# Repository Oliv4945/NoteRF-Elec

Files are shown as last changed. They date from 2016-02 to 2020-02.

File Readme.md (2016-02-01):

# NodeRF

RF sensors and actuators based on ATMega328 and RFM69hw from hopeRF.  
Arduino bootloader is used in order to use all available libraries

## NoteGateway
Gateway with serial output. It just collects data from RF sensors and send it through serial link.  
Configuration is explained in configuration.h file

Serial messages are really simple for now and formated like `sensorNumber|dataType|Data1|Data2|DataX|batteryLevel|RSSI`  
For example, the sensor N°5, type temperature (16.50°C) and humidity (55.3%) with a battery level of 3.98V is `5|1|1650|5530|398|-53`

## NoteSensor
Sensors' code.  
You just have to set config.h to suit your needs. Also uncommenting a `#define DATA_SENSORNAME` will activate it.

## Schematics
Hardware source files made with Eagle 7.3.0 + [Spakfun library](https://github.com/sparkfun/SparkFun-Eagle-Libraries)

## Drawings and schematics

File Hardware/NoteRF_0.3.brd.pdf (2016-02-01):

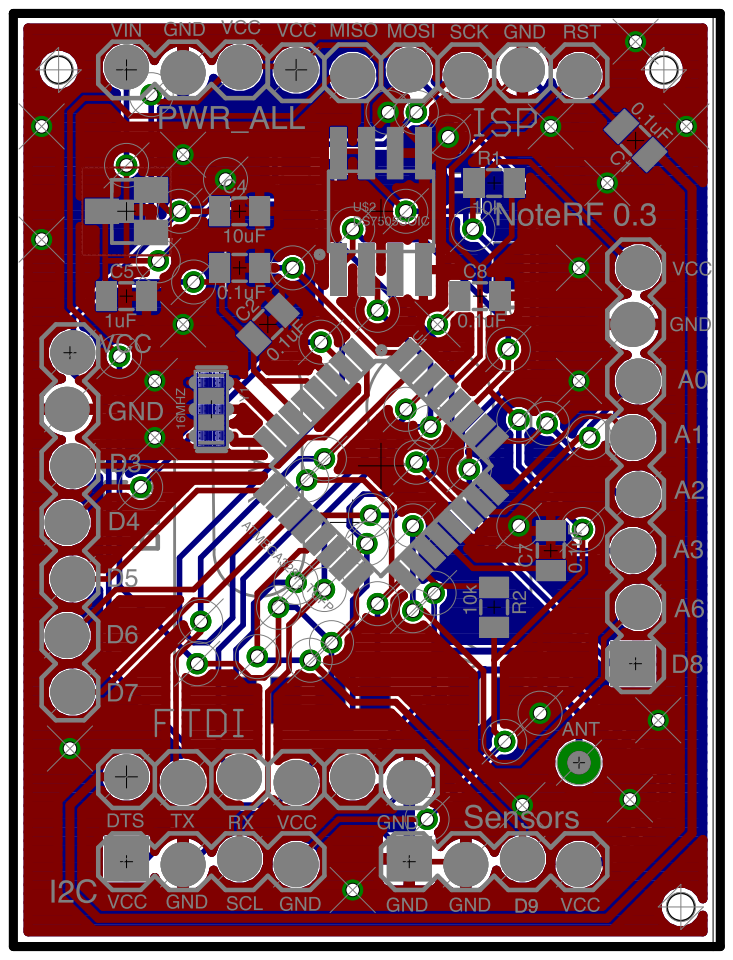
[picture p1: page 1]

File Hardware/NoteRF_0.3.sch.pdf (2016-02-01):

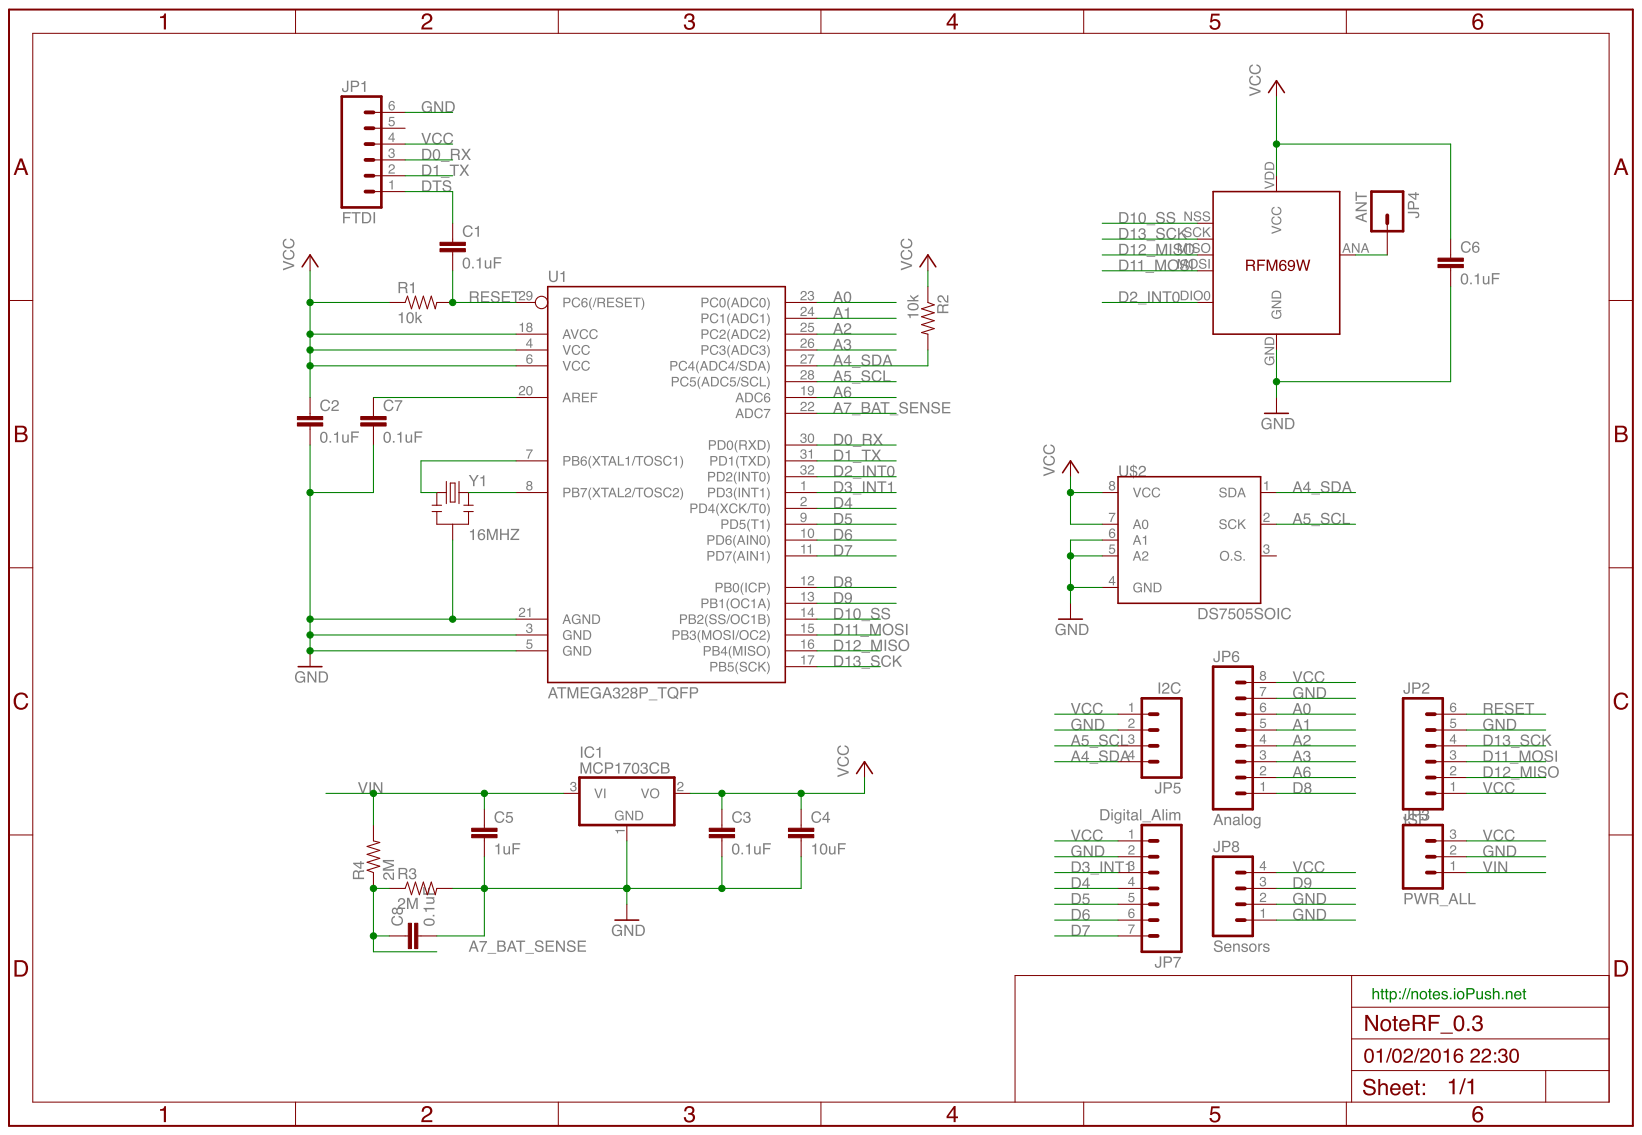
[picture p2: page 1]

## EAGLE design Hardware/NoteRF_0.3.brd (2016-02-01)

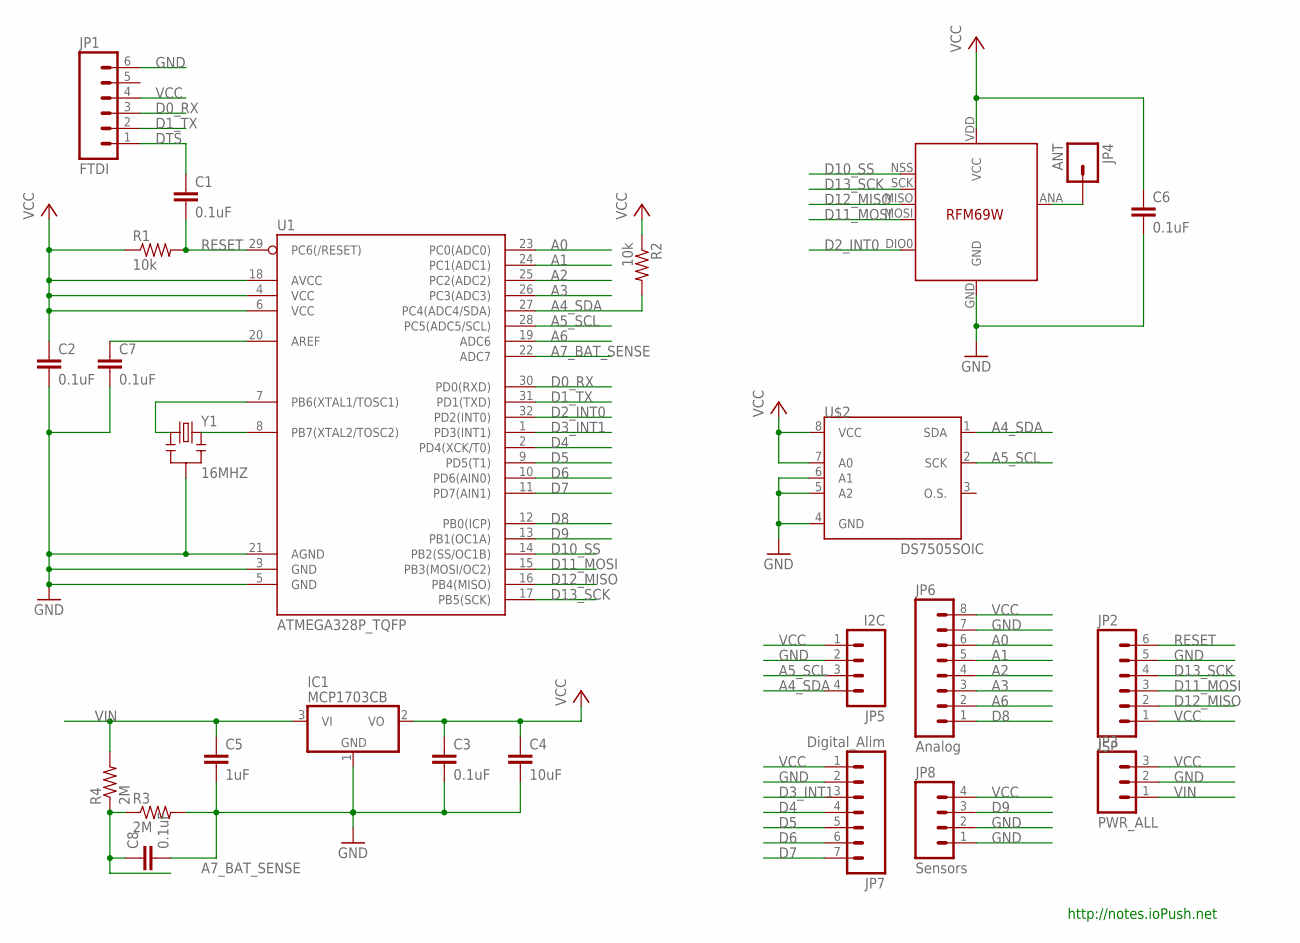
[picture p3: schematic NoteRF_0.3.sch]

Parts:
C1, C2, C3, C6, C7, C8: 0.1uF; 0805
C4: 10uF; 0805
C5: 1uF; 0805
IC1: MCP1703CB; SOT23
JP1: FTDI; 1X06_LOCK
JP2: ISP; 1X06_LOCK
JP3: PWR_ALL; 1X03_LOCK
JP4: ANT; 1X01NS-KIT
JP5: I2C; 1X04_LOCK
JP6: Analog; 1X08_LOCK
JP7: Digital_Alim; 1X07_LOCK
JP8: Sensors; 1X04_LOCK
R1, R2: 10k; 0805
R3, R4: 2M; 0805
U1: ATMEGA328P_TQFP; TQFP32-08
U$1: RFM69; RFM69W-MINPADS
U$2: DS7505SOIC; SO08
Y1: 16MHZ; RESONATOR-SMD

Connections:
A0: JP6.6, U1.23 (PC0(ADC0))
A1: JP6.5, U1.24 (PC1(ADC1))
A2: JP6.4, U1.25 (PC2(ADC2))
A3: JP6.3, U1.26 (PC3(ADC3))
A4_SDA: JP5.4, R2.2, U1.27 (PC4(ADC4/SDA)), U$2.1 (SDA)
A5_SCL: JP5.3, U1.28 (PC5(ADC5/SCL)), U$2.2 (SCK)
A6: JP6.2, U1.19 (ADC6)
A7_BAT_SENSE: C8.1, R3.1, R4.1, U1.22 (ADC7)
D0_RX: JP1.3, U1.30 (PD0(RXD))
D1_TX: JP1.2, U1.31 (PD1(TXD))
D2_INT0: U1.32 (PD2(INT0)), U$1.DIO0
D3_INT1: JP7.3, U1.1 (PD3(INT1))
D4: JP7.4, U1.2 (PD4(XCK/T0))
D5: JP7.5, U1.9 (PD5(T1))
D6: JP7.6, U1.10 (PD6(AIN0))
D7: JP7.7, U1.11 (PD7(AIN1))
D8: JP6.1, U1.12 (PB0(ICP))
D9: JP8.3, U1.13 (PB1(OC1A))
D10_SS: U1.14 (PB2(SS/OC1B)), U$1.NSS (SEL)
D11_MOSI: JP2.3, U1.15 (PB3(MOSI/OC2)), U$1.MOSI
D12_MISO: JP2.2, U1.16 (PB4(MISO)), U$1.MISO
D13_SCK: JP2.4, U1.17 (PB5(SCK)), U$1.SCK
DTS: C1.1, JP1.1
GND: C2.2, C3.2, C4.2, C5.2, C6.2, C7.2, C8.2, IC1.1 (GND), JP1.6, JP2.5, JP3.2, JP5.2, JP6.7, JP7.2, JP8.1, JP8.2, R3.2, U1.3 (GND), U1.5 (GND), U1.21 (AGND), U$1.GND, U$2.4 (GND), U$2.5 (A2), U$2.6 (A1), Y1.2
unnamed: JP4.1, U$1.ANA (ANT)
unnamed: C7.1, U1.20 (AREF)
unnamed: U1.8 (PB7(XTAL2/TOSC2)), Y1.3
unnamed: U1.7 (PB6(XTAL1/TOSC1)), Y1.1
RESET: C1.2, JP2.6, R1.2, U1.29 (PC6(/RESET))
VCC: C2.1, C3.1, C4.1, C6.1, IC1.2 (VO), JP1.4, JP2.1, JP3.3, JP5.1, JP6.8, JP7.1, JP8.4, R1.1, R2.1, U1.4 (VCC), U1.6 (VCC), U1.18 (AVCC), U$1.VDD (VCC), U$2.7 (A0), U$2.8 (VCC)
VIN: C5.1, IC1.3 (VI), JP3.1, R4.2

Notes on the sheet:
http://notes.ioPush.net

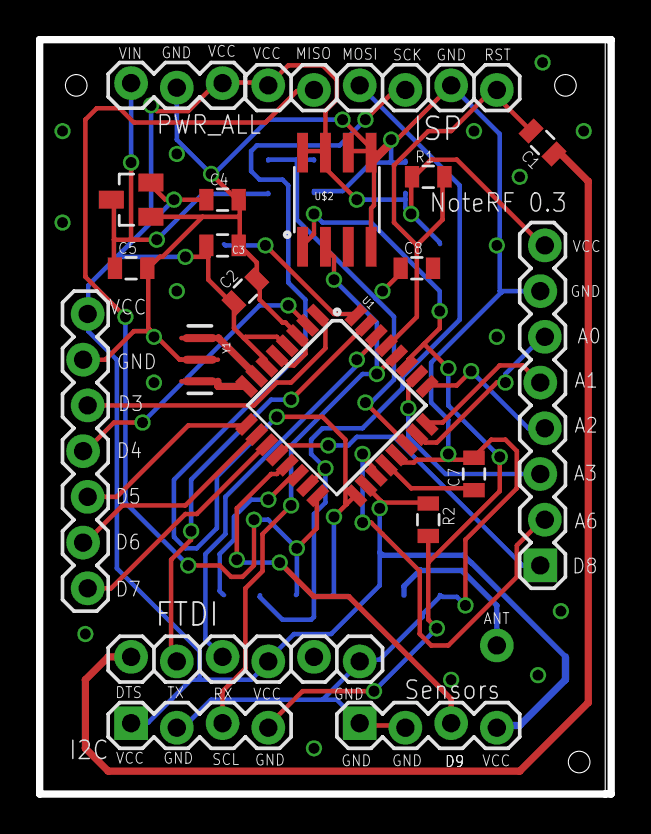
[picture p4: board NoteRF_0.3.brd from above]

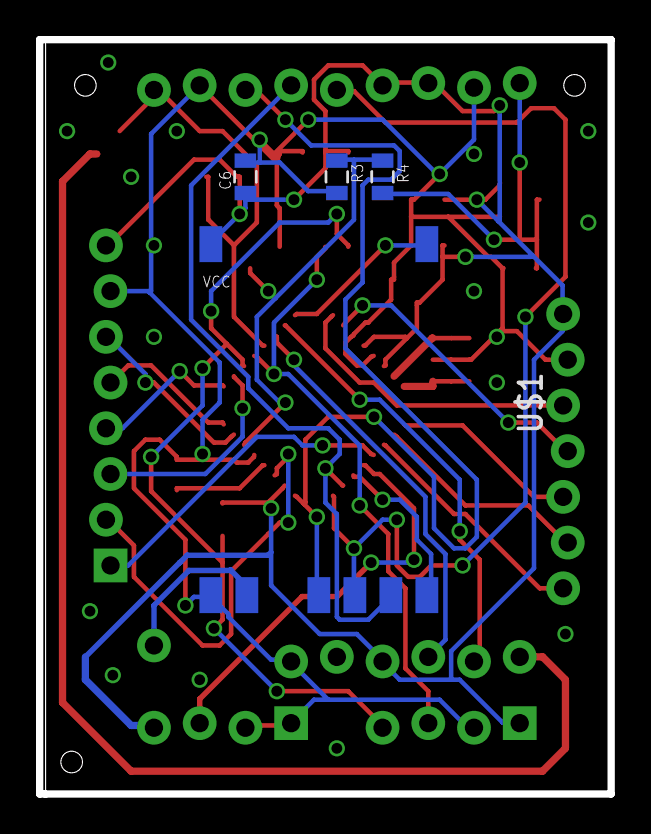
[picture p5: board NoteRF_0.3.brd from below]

Board: 2 copper layers, 31.8 x 41.9 mm, 25 parts (4 on the bottom side), 31 nets.

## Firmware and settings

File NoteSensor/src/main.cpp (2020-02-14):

// Includes
#include <Arduino.h>
#include <RFM69.h>    // Get it here: https://www.github.com/lowpowerlab/rfm69
#include <SPI.h>
#include <LowPower.h>
#include "configuration.h"
#ifdef DATA_DHT22
  #include <dht.h>
#endif
#ifdef DATA_TELEINFOCLIENT
  #include <SoftwareSerial.h>
  #include <TeleInfoClient.h>
#endif
#ifdef DATA_BMP
  // From https://github.com/jrowberg/i2cdevlib/tree/master/Arduino/BMP085
  #include "Wire.h"
  #include "I2Cdev.h"
  #include "BMP085.h"
#endif
#ifdef DATA_VL53L0X
  #include <Wire.h>
  #include <VL53L0X.h>
#endif

// Activate/desactivate debug with only one #define
// From low power lab :)
#ifdef DEBUG_ON 
  #define DEBUG( input )    { Serial.print(input); delay(1); }
  #define DEBUGDec( input ) { Serial.print( input, DEC); delay(1); }
  #define DEBUGHex( input ) { Serial.print(input, HEX); delay(1); }
  #define DEBUGln( input )  { Serial.println(input); delay(1); }
#else
  #define DEBUG(input);
  #define DEBUGDec( input )
  #define DEBUGHex( input )
  #define DEBUGln(input);
#endif


// Others - This data has not to be configured
#define DATA_STRING    0


// Structures
#ifdef DATA_DHT22
  struct DHT22Data {
    int16_t temperature;
    uint16_t humidity;
  };
#endif
#ifdef DATA_TELEINFOCLIENT
  struct TeleInfoClientData {
    unsigned long indexHC;
    unsigned long indexHP;
    unsigned int iinst;
    unsigned int papp;
  };
#endif
#ifdef DATA_DS18B20
  struct DS18B20Data {
    int16_t temperature;
    uint16_t humidity;
  };
#endif
#ifdef DATA_BMP
  struct BMPData {
    int16_t temperature;
    uint32_t pressure;
  };
#endif

// Objects and globals
RFM69 radio;
#ifdef DATA_DHT22
  dht DHT22;
#endif
#ifdef DATA_TELEINFOCLIENT
  TeleInfoClient tic( 3, 10, 11 );
#endif
#ifdef DATA_BMP
  BMP085 barometer;
#endif
#ifdef DATA_INTERRUPT
  uint8_t interruptData;
#endif

#ifdef DATA_VL53L0X
  VL53L0X tof;
#endif
  

void setup() {
  
  // Serial init.
  #ifdef DEBUG_ON
    Serial.begin( SERIAL_BAUD );
  #endif
  DEBUG( "SensorRF - NodeID : " );
  DEBUGln( RFM_NODEID );
  
  // RFM69 init.
  DEBUG( "RFM69 - Initialisation" );
  radio.initialize( RFM_FREQUENCY, RFM_NODEID, RFM_NETWORKID );
  DEBUG( "RFM69 - Initialised" );
  #ifdef RFM_IS_RFM69HW
    radio.setHighPower( true );
  #endif
  radio.encrypt( RFM_ENCRYPTKEY );
  radio.setPowerLevel( RFM_POWER_LEVEL );
  //radio.setFrequency( 919000000 ); //set frequency to some custom frequency - TBC
  char buff[50];
  sprintf( buff, "\nTransmitting at %d Mhz...", RFM_FREQUENCY==RF69_433MHZ ? 433 : RFM_FREQUENCY==RF69_868MHZ ? 868 : 915 );
  DEBUGln( buff );
  delay( 10 );
  
  
  #ifdef DATA_DHT22
    // Pins
    pinMode( PIN_DHT22_POWER, OUTPUT );
    // DHT22 check
    digitalWrite( PIN_DHT22_POWER, HIGH );                   // Power the DHT22
    LowPower.powerDown( SLEEP_4S, ADC_OFF, BOD_OFF );        // Wait DHT22 start
    int chk = DHT22.read22( PIN_DHT22_DATA );
    switch ( chk ) {
    case DHTLIB_OK:
        DEBUG("DHT22 - OK,\t");
        // DISPLAY DATA
        DEBUG( DHT22.humidity );
        DEBUG( "% ,\t" );
        DEBUG( DHT22.temperature );
        DEBUGln( "C" );
        break;
    case DHTLIB_ERROR_CHECKSUM:
        DEBUG("DHT22 - Checksum error,\t");
        break;
    case DHTLIB_ERROR_TIMEOUT:
        DEBUG("DHT22 - Time out error,\t");
        break;
    case DHTLIB_ERROR_CONNECT:
        DEBUG("DHT22 - Connect error,\t");
        break;
    case DHTLIB_ERROR_ACK_L:
        DEBUG("DHT22 - Ack Low error,\t");
        break;
    case DHTLIB_ERROR_ACK_H:
        DEBUG("DHT22 - Ack High error,\t");
        break;
    default:
        DEBUG("DHT22 - Unknown error,\t");
        break;
    }
    // digitalWrite( PIN_DHT22_POWER, 0);                // Unpower the DHT2 - TBC might be before, check library
    LowPower.powerDown( SLEEP_1S, ADC_OFF, BOD_OFF );    // Avoid error on first reading in loop()
  #endif
  
  #ifdef DATA_MOISTURE_SENSOR
    // Setup the outputs
    pinMode( PIN_MOISTURE_POWER, OUTPUT );
    pinMode( PIN_MOISTURE_DATA, INPUT );
    digitalWrite( PIN_MOISTURE_POWER, OUTPUT );
  #endif
  #ifdef DATA_BMP
    Wire.begin();
    barometer.initialize();
    #ifdef DEBUG_ON
      Serial.print( barometer.testConnection() ? "BMP - Connection successful" : "BMP - Connection failed") ;
    #endif
  #endif
  #ifdef DATA_INTERRUPT
    pinMode(3, INPUT);
  #endif
  #ifdef DATA_VL53L0X
      tof.init();
      tof.setTimeout(VL53L0X_TIMING_REC_us*2/1000);
      tof.setMeasurementTimingBudget(VL53L0X_TIMING_REC_us);

      // Set long range
      // lower the return signal rate limit (default is 0.25 MCPS)
      tof.setSignalRateLimit(0.1);
      // increase laser pulse periods (defaults are 14 and 10 PCLKs)
      tof.setVcselPulsePeriod(VL53L0X::VcselPeriodPreRange, 18);
      tof.setVcselPulsePeriod(VL53L0X::VcselPeriodFinalRange, 14);
  #endif
}

unsigned int readVin() {
  int Vin;
  // Vin = analogRead( A7 )*3.3/1024*2*100*417/406; // Read value*3.3/1024, Times 2 for resistors, times 100 for centivolts, *417/406 for calibration
  Vin = (unsigned int) analogRead( A7 )*0.6619939193; // TBC - Add calibration value in configuration.h
  return Vin;
  
}
// http://provideyourown.com/2012/secret-arduino-voltmeter-measure-battery-voltage/
int readVcc() {
  // Read 1.1V reference against AVcc
  // set the reference to Vcc and the measurement to the internal 1.1V reference
  #if defined(__AVR_ATmega32U4__) || defined(__AVR_ATmega1280__) || defined(__AVR_ATmega2560__)
    ADMUX = _BV(REFS0) | _BV(MUX4) | _BV(MUX3) | _BV(MUX2) | _BV(MUX1);
  #elif defined (__AVR_ATtiny24__) || defined(__AVR_ATtiny44__) || defined(__AVR_ATtiny84__)
    ADMUX = _BV(MUX5) | _BV(MUX0);
  #elif defined (__AVR_ATtiny25__) || defined(__AVR_ATtiny45__) || defined(__AVR_ATtiny85__)
    ADMUX = _BV(MUX3) | _BV(MUX2);
  #else
    ADMUX = _BV(REFS0) | _BV(MUX3) | _BV(MUX2) | _BV(MUX1);
  #endif  
 
  delay( 2 );                       // Wait for Vref to settle
  ADCSRA |= _BV( ADSC );            // Start conversion
  while (bit_is_set(ADCSRA,ADSC));  // Measuring
 
  uint8_t low  = ADCL;              // Must read ADCL first - it then locks ADCH  
  uint8_t high = ADCH;              // Unlocks both
 
  int result = (high<<8) | low;
 
  result = 109881L / result;        // Calculate Vcc (in centiV); 1125300 = 1.1*etalonnage*1023*1000
  return result;                    // Vcc in millivolts
}


// Interruption sub routine on pin 3
#ifdef DATA_INTERRUPT
  void isr_D3() {
    interruptData = 1;
  }
#endif

void loop() {
  // Variable declaration
  char buffer[50];
  boolean requestACK;
  uint8_t bufflen;
  int time;
  uint16_t vccCentiVolt;
  uint8_t dataType;
  int32_t lastMicros;
  
  #ifdef DATA_DHT22
    struct DHT22Data dht22Data;
    int dht22_check;
  #endif
  #ifdef DATA_TELEINFOCLIENT
    struct TeleInfoClientData ticData;
  #endif
  #ifdef DATA_MOISTURE_SENSOR
    uint8_t dataMoisture;
  #endif
  #ifdef DATA_BMP
    struct BMPData bmpData;
  #endif
  
  // Variable initialisation
  requestACK = false;
  time = 0;
  #ifdef DATA_INTERRUPT
    interruptData = 0;
  #endif
  
  // Send message to the gateway
  bufflen = sizeof( uint8_t );
  dataType = DATA_STRING;
  memcpy( buffer, &dataType, bufflen );
  sprintf( buffer+bufflen, "%s", "Start" );
  bufflen = bufflen + strlen( "Start" );
  
  if ( radio.sendWithRetry( RFM_GATEWAYID, &buffer, bufflen ) ) {
    DEBUGln( "RFM - OK" );
  } else {
    DEBUGln( "RFM - NOK" );
  }
  
  
  while (1) {
    // Reset sending buffer length
    bufflen = 0;
    
    // Read VCC level
    #ifdef BATTERY_VCC
      vccCentiVolt = (uint16_t) readVcc();
    #endif
    #ifdef BATTERY_VIN
      vccCentiVolt = (uint16_t) readVin();
    #endif
    DEBUG( "VCC : " ); DEBUG( vccCentiVolt ); DEBUGln( " cV");
  
    #ifdef DATA_DHT22
      // Read DHT22
      // digitalWrite( PIN_DHT22_POWER, 1);                // Power the DHT22
      // LowPower.powerDown( SLEEP_8S, ADC_OFF, BOD_OFF ); // Wait DHT22 start
      dht22_check = DHT22.read22( PIN_DHT22_DATA );   
      if ( dht22_check == DHTLIB_OK ) {    
        dht22Data.temperature = (int16_t) (DHT22.temperature*100.0);
        dht22Data.humidity = (uint16_t) (DHT22.humidity*100.0);
        // digitalWrite( PIN_DHT22_POWER, 0);   // Unpower the DHT22
        
        // Add data to the buffer
        dataType = DATA_DHT22;
        memcpy( buffer+bufflen, &dataType, sizeof( uint8_t ) );
        bufflen = bufflen + sizeof( uint8_t );
        memcpy( buffer+bufflen, &dht22Data, sizeof( struct DHT22Data ) );
        bufflen = bufflen + sizeof( struct DHT22Data );
        // Prepare buffer
        memcpy( buffer+bufflen, &vccCentiVolt, sizeof( uint16_t) );
        bufflen = bufflen + sizeof( uint16_t);
        DEBUG( "Bufflen : " );
        DEBUGln( bufflen );
        
        if ( radio.sendWithRetry( RFM_GATEWAYID, &buffer, bufflen ) ) {
          DEBUGln( "RFM - OK" );
        } else {
          DEBUGln( "RFM - NOK" );
        }
      
      } else {  // TBC - Send error via RF
        DEBUG( "DHT22 - Check NOK : " );
        DEBUGln( dht22_check );
      }
    #endif
    
    // TBC - Avoid sending VCC twice - Separate data ?
    
    #ifdef DATA_TELEINFOCLIENT // TBC - Add timeout
      tic.getValues();
      ticData.indexHP = tic.hchp;
      ticData.indexHC = tic.hchc;
      ticData.iinst = tic.iinst;
      ticData.papp = tic.papp;
      DEBUG( "PAPP - ");
      DEBUGln( tic.papp );
      
      
      // Add data to the buffer
      bufflen = 0;
      dataType = DATA_TELEINFOCLIENT;
      memcpy( buffer+bufflen, &dataType, sizeof( uint8_t ) );
      bufflen = bufflen + sizeof( uint8_t );
      memcpy( buffer+bufflen, &ticData, sizeof( struct TeleInfoClientData ) );
      bufflen = bufflen + sizeof( struct TeleInfoClientData );
      memcpy( buffer+bufflen, &vccCentiVolt, sizeof( uint16_t) );
      bufflen = bufflen + sizeof( uint16_t);
      if ( radio.sendWithRetry( RFM_GATEWAYID, &buffer, bufflen ) ) {
        DEBUGln( "RFM - OK" );
      } else {
        DEBUGln( "RFM - NOK" );
      }
    #endif

    /*****      MOISTURE SENSOR     ******/
    #ifdef DATA_MOISTURE_SENSOR
      // Power up the moisture sensor
      digitalWrite( PIN_MOISTURE_POWER, HIGH );
      // Wait some time for the current to settle - time TBC
      delay( 100 );
      // Read data and divide it by 4 to fit inside 1 byte, enough for the required precision
      dataMoisture = analogRead( PIN_MOISTURE_DATA )/4;
      // Power down the sensor
      digitalWrite( PIN_MOISTURE_POWER, LOW );
      DEBUG( "MOISTURE - Value : " );
      DEBUGln( dataMoisture );
      
      // Add data to the buffer
      bufflen = 0;
      dataType = DATA_MOISTURE_SENSOR;
      memcpy( buffer+bufflen, &dataType, sizeof( uint8_t ) );
      bufflen = bufflen + sizeof( uint8_t );
      memcpy( buffer+bufflen, &dataMoisture, sizeof( uint8_t ) );
      bufflen = bufflen + sizeof( uint8_t );
      memcpy( buffer+bufflen, &vccCentiVolt, sizeof( uint16_t) );
      bufflen = bufflen + sizeof( uint16_t);
      if ( radio.sendWithRetry( RFM_GATEWAYID, &buffer, bufflen ) ) {
        DEBUGln( "RFM - OK" );
      } else {
        DEBUGln( "RFM - NOK" );
      }
    #endif


    /*****      BAROMETRIC SENSOR     ******/
    #ifdef DATA_BMP
      // Request temperature
      barometer.setControl( BMP085_MODE_TEMPERATURE );
      // Wait appropriate time for conversion (4.5ms delay)
      lastMicros = micros();
      while (micros() - lastMicros < barometer.getMeasureDelayMicroseconds());
      // Read calibrated temperature value in degrees Celsius
      bmpData.temperature = ( (int16_t) (barometer.getTemperatureC()*100.0) );
      // Request pressure (3x oversampling mode, high detail, 23.5ms delay)
      barometer.setControl( BMP085_MODE_PRESSURE_3 );
      while (micros() - lastMicros < barometer.getMeasureDelayMicroseconds());
      // Read calibrated pressure value in Pascals (Pa)
      bmpData.pressure = ( (uint32_t) barometer.getPressure() );
      // Display values
      DEBUG( "BMP - Temperature : " );
      DEBUGln( bmpData.temperature );
      DEBUG( "BMP - Pressure : " );
      DEBUGln( bmpData.pressure );
      
      // Add data to the buffer
      bufflen = 0;
      dataType = DATA_BMP;
      memcpy( buffer+bufflen, &dataType, sizeof( uint8_t ) );
      bufflen = bufflen + sizeof( uint8_t );
      memcpy( buffer+bufflen, &bmpData, sizeof( struct BMPData ) );
      bufflen = bufflen + sizeof( struct BMPData );
      // Prepare buffer
      memcpy( buffer+bufflen, &vccCentiVolt, sizeof( uint16_t) );
      bufflen = bufflen + sizeof( uint16_t);
      DEBUG( "Bufflen : " );
      DEBUGln( bufflen );
      if ( radio.sendWithRetry( RFM_GATEWAYID, &buffer, bufflen ) ) {
        DEBUGln( "RFM - OK" );
      } else {
        DEBUGln( "RFM - NOK" );
      }
    #endif


    #ifdef DATA_INTERRUPT
      // Send interrupt on wake up
      if (interruptData != 0) {
        DEBUG( "INTERRUPT - Triggered : " );
        DEBUGln( interruptData );
        
        // Add data to the buffer
        bufflen = 0;
        dataType = DATA_INTERRUPT;
        memcpy( buffer+bufflen, &dataType, sizeof( uint8_t ) );
        bufflen = bufflen + sizeof( uint8_t );
        memcpy( buffer+bufflen, &interruptData, sizeof( uint8_t ) );
        bufflen = bufflen + sizeof(  uint8_t );
        // Prepare buffer
        memcpy( buffer+bufflen, &vccCentiVolt, sizeof( uint16_t) );
        bufflen = bufflen + sizeof( uint16_t);
        DEBUG( "Bufflen : " );
        DEBUGln( bufflen );
        if ( radio.sendWithRetry( RFM_GATEWAYID, &buffer, bufflen ) ) {
          DEBUGln( "RFM - OK" );
        } else {
          DEBUGln( "RFM - NOK" );
        }
        
        interruptData = 0;
        
      }
    #endif

    #ifdef DATA_VL53L0X
      uint16_t distance = tof.readRangeSingleMillimeters();
      if (tof.timeoutOccurred()) {
        DEBUGln("TOF - Timeout");
      } else {
        DEBUG("TOF - Distance: ");
        DEBUG(distance);
        DEBUGln(" mm");
      }
      // Transmit even in case of timeout (0xFFFF)
      
      // Add data to the buffer
      bufflen = 0;
      dataType = DATA_VL53L0X;
      memcpy( buffer+bufflen, &dataType, sizeof( uint8_t ) );
      bufflen = bufflen + sizeof( uint8_t );
      memcpy( buffer+bufflen, &distance, sizeof( uint16_t ) );
      bufflen = bufflen + sizeof( uint16_t );
      // Prepare buffer
      memcpy( buffer+bufflen, &vccCentiVolt, sizeof( uint16_t) );
      bufflen = bufflen + sizeof( uint16_t);
      DEBUG( "Bufflen : " );
      DEBUGln( bufflen );
      if ( radio.sendWithRetry( RFM_GATEWAYID, &buffer, bufflen ) ) {
        DEBUGln( "RFM - OK" );
      } else {
        DEBUGln( "RFM - NOK" );
      }
    #endif
    
    
    // Put radio in sleep mode
    #ifndef DATA_INTERRUPT
        radio.sleep();
      // Wait 1 min minus 2 secondes - TBC for a sending every minute
      while ( time < 7 ) {
        LowPower.powerDown( SLEEP_8S, ADC_OFF, BOD_OFF );
        time++;
        DEBUG( "Time : "); DEBUGln( time );
      }
      LowPower.powerDown( SLEEP_2S, ADC_OFF, BOD_OFF );
      time = 0;
    #endif
    #ifdef DATA_INTERRUPT
      attachInterrupt(digitalPinToInterrupt(3), isr_D3, RISING);
      LowPower.powerDown(SLEEP_FOREVER, ADC_OFF, BOD_OFF); 
      // Disable external pin interrupt on wake up pin.
      detachInterrupt(0);
    #endif
  }
}

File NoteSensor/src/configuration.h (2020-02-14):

#ifndef CONFIGURATION_H
  #define CONFIGURATION_H
  
  
  /*************          RF configuration      *************/
  #define RFM_NODEID        4     // Unique for each node on same network
  #define RFM_NETWORKID     110    // The same on all nodes that talk to each other
  #define RFM_GATEWAYID     0      // Gateway to reach
  #define RFM_FREQUENCY     RF69_433MHZ
  #define RFM_ENCRYPTKEY    "sampleEncryptKey" // Exactly the same 16 characters/bytes on all nodes!
  #define RFM_IS_RFM69HW           // Uncomment only for RFM69HW! Leave out if you have RFM69W!
  #define RFM_ACK_TIME      30     // max # of ms to wait for an ack
  #define RFM_POWER_LEVEL   32     // Set power level - TBC for RFM96HW [0-32]
  
  /*************          Node configuration      *************/
  // #define BATTERY_VCC      // Sense Arduino's VCC battery with 1.1V internal ref
  #define BATTERY_VIN         // Sense battery with divider on A7
  
  // Data types  -  Uncomment DATA_XXX to activate it
  // #define DATA_DHT22      1 
  #define PIN_DHT22_DATA  4
  #define PIN_DHT22_POWER 5
  
  // #define DATA_TELEINFOCLIENT 2
  #define PIN_TELEINFOCLIENT 3
  
  // #define DATA_DS18B20   3
  #define PIN_DS18B20    6
  
  // #define DATA_MOISTURE_SENSOR 4
  #define PIN_MOISTURE_DATA A1
  #define PIN_MOISTURE_POWER A0

  
  // #define DATA_BMP 5  // Barometer - Works with Bosh BMPXXX

  // #define DATA_INTERRUPT 6

  // #define DATA_VL53L0X 7
  #define VL53L0X_TIMING_REC_us 150000 // Precision vs time. (us)
  
  // Others
  #define DEBUG_ON              // Uncomment to activate debug
  #define SERIAL_BAUD   115200  // Set serial communication speed
  

#endif

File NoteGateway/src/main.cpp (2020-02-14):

// Sample RFM69 receiver/gateway sketch, with ACK and optional encryption
// Passes through any wireless received messages to the serial port & responds to ACKs
// It also looks for an onboard FLASH chip, if present
// Library and code by Felix Rusu - felix@lowpowerlab.com
// Get the RFM69 and SPIFlash library at: https://github.com/LowPowerLab/
#include <Arduino.h>
#include <RFM69.h>    //get it here: https://www.github.com/lowpowerlab/rfm69
#include <SPI.h>
#include "configuration.h"




// Data types
#define DATA_STRING    0
#define DATA_DHT22     1
#define DATA_TELEINFOCLIENT 2
#define DATA_DS18B20   3
#define DATA_MOISTURE_SENSOR 4
#define DATA_BMP 5
#define DATA_INTERRUPT 6
#define DATA_VL53L0X 7




// Structures
struct DHT22Data {
  int16_t temperature;
  uint16_t humidity;
};
struct DS18B20Data {
  int16_t temperature;
  uint16_t humidity;
};
struct TeleInfoClientData {
  unsigned long indexHC;
  unsigned long indexHP;
  unsigned int iinst;
  unsigned int papp;
};
struct BMPData {
  int16_t temperature;
  uint32_t pressure;
};

RFM69 radio;
bool promiscuousMode = false; // Set to 'true' to sniff all packets on the same network

void setup() {
  Serial.begin(SERIAL_BAUD);
  delay(10);
  Serial.print( "Start" );
  radio.initialize(FREQUENCY,NODEID,NETWORKID);
#ifdef IS_RFM69HW
  radio.setHighPower( true ); //only for RFM69HW!
#endif
  radio.encrypt(ENCRYPTKEY);
  radio.promiscuous(promiscuousMode);
  //radio.setFrequency(919000000);
  char buff[50];
  sprintf(buff, "\nListening at %d Mhz, NetworkID : %d, GatewayID : %d", FREQUENCY==RF69_433MHZ ? 433 : FREQUENCY==RF69_868MHZ ? 868 : 915, NETWORKID, NODEID);
  Serial.println(buff);
}

byte ackCount=0;
uint32_t packetCount = 0;
void loop() {

  char bufferRFM[ 62 ];
  char bufferSerial[ 100 ];
  char* bufferPointer;
  byte i;
  struct DHT22Data dht22Data;
  struct TeleInfoClientData ticData;
  uint8_t dataMoisture;
  uint16_t sensorBattery;
  struct BMPData bmpData;
  uint8_t interruptData;
  uint16_t vl53l0xData;


  while (1) {

    if ( radio.receiveDone() ) {
      // Start a new frame for Node-Red
      Serial.print( "\n" );
      for ( i = 0; i < radio.DATALEN; i++ ) {
        bufferRFM[i] =  (char) radio.DATA[i]; // TBC - memcpy, direct ?
      }
      bufferRFM[ i ] = '\0';



      // Select the message ID - TBC - Switch( bufferRFM[0] );
      if ( bufferRFM[0] == DATA_STRING ) {
        Serial.print( '[' ); 
        Serial.print( radio.SENDERID, DEC ); 
        Serial.print( "] " );
        bufferPointer = bufferRFM + 1;
        Serial.print( bufferPointer );
        Serial.print( '\n' );
      }
      if ( bufferRFM[0] == DATA_DHT22 ) {
        bufferPointer = bufferRFM + 1;
        memcpy( &dht22Data, bufferPointer, sizeof( struct DHT22Data) );
        bufferPointer += sizeof( struct DHT22Data);
        memcpy( &sensorBattery, bufferPointer, sizeof( uint16_t ) );
        sprintf( bufferSerial, "%d|%d|%d|%d|%d|%d\n", radio.SENDERID, DATA_DHT22, dht22Data.temperature, dht22Data.humidity, sensorBattery, radio.RSSI );
        Serial.print( bufferSerial );
      }
      if ( bufferRFM[0] == DATA_TELEINFOCLIENT ) {
        bufferPointer = bufferRFM + 1;
        memcpy( &ticData, bufferPointer, sizeof( struct TeleInfoClientData ) );
        bufferPointer += sizeof( struct TeleInfoClientData);
        memcpy( &sensorBattery, bufferPointer, sizeof( uint16_t ) );
        sprintf( bufferSerial, "%d|%d|%lu|%lu|%u|%u|%d|%d\n", radio.SENDERID, DATA_TELEINFOCLIENT, ticData.indexHP, ticData.indexHC, ticData.iinst, ticData.papp, sensorBattery, radio.RSSI );
        Serial.print( bufferSerial );
      }
      if ( bufferRFM[0] == DATA_MOISTURE_SENSOR ) {
        bufferPointer = bufferRFM + 1;
        memcpy( &dataMoisture, bufferPointer, sizeof( uint8_t ) );
        bufferPointer += sizeof( uint8_t );
        memcpy( &sensorBattery, bufferPointer, sizeof( uint16_t ) );
        sprintf( bufferSerial, "%d|%d|%u|%d|%d\n", radio.SENDERID, DATA_MOISTURE_SENSOR, dataMoisture, sensorBattery, radio.RSSI );
        Serial.print( bufferSerial );
      }
      if ( bufferRFM[0] == DATA_DS18B20 ) {
        bufferPointer = bufferRFM + 1;
        memcpy( &dataMoisture, bufferPointer, sizeof( uint16_t ) );
        bufferPointer += sizeof( uint16_t );
        memcpy( &sensorBattery, bufferPointer, sizeof( uint16_t ) );
        sprintf( bufferSerial, "%d|%d|%d|%d|%d\n", radio.SENDERID, DATA_DS18B20, dataMoisture, sensorBattery, radio.RSSI );
        Serial.print( bufferSerial );
      }
      if ( bufferRFM[0] == DATA_BMP ) {
        bufferPointer = bufferRFM + 1;
        memcpy( &bmpData, bufferPointer, sizeof( struct BMPData ) );
        bufferPointer += sizeof( BMPData );
        memcpy( &sensorBattery, bufferPointer, sizeof( uint16_t ) );
        sprintf( bufferSerial, "%d|%d|%d|%lu|%d|%d\n", radio.SENDERID, DATA_BMP, bmpData.temperature, bmpData.pressure, sensorBattery, radio.RSSI );
        Serial.print( bufferSerial );
      }
      if ( bufferRFM[0] == DATA_INTERRUPT ) {
        bufferPointer = bufferRFM + 1;
        memcpy( &interruptData, bufferPointer, sizeof( uint8_t ) );
        bufferPointer += sizeof( uint8_t );
        memcpy( &sensorBattery, bufferPointer, sizeof( uint16_t ) );
        sprintf( bufferSerial, "%d|%d|%d|%d|%d\n", radio.SENDERID, DATA_INTERRUPT, interruptData, sensorBattery, radio.RSSI );
        Serial.print( bufferSerial );
      }
      if ( bufferRFM[0] == DATA_VL53L0X ) {
        bufferPointer = bufferRFM + 1;
        memcpy( &vl53l0xData, bufferPointer, sizeof( uint16_t ) );
        bufferPointer += sizeof( uint16_t );
        memcpy( &sensorBattery, bufferPointer, sizeof( uint16_t ) );
        sprintf( bufferSerial, "%d|%d|%d|%d|%d\n", radio.SENDERID, DATA_VL53L0X, vl53l0xData, sensorBattery, radio.RSSI );
        Serial.print( bufferSerial );
      }


      Serial.print('[');
      Serial.print(radio.SENDERID, DEC);
      Serial.print("] ");
      if (promiscuousMode)
      {
        Serial.print("to [");
        Serial.print(radio.TARGETID, DEC);
        Serial.print("] ");
      }
      Serial.print( " - radio.DATALEN : " );
      Serial.print( radio.DATALEN );
      if (radio.ACKRequested())
      {
        byte theNodeID = radio.SENDERID;
        radio.sendACK();
        Serial.print(" - ACK sent.");

        // When a node requests an ACK, respond to the ACK
        // and also send a packet requesting an ACK (every 3rd one only)
        // This way both TX/RX NODE functions are tested on 1 end at the GATEWAY
        /* if (ackCount++%3==0)
         {
         Serial.print(" Pinging node ");
         Serial.print(theNodeID);
         Serial.print(" - ACK...");
         delay(3); //need this when sending right after reception .. ?
         if (radio.sendWithRetry(theNodeID, "ACK TEST", 8, 0))  // 0 = only 1 attempt, no retries
         Serial.print("ok!");
         else Serial.print("nothing");
         }*/
      }
      Serial.print( "\n" );
    }
  }
}

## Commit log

2015-03-07 Gateway and node Add "configuration.h" file for improving configuration Add #define DATA_SENSOR for each sensor, improving configuration
    Gateway
    Send data type through serial link to allow the receiver to understand what is send
    [configuration.h]
2015-03-07 Improve NoteSensor readability
    [configuration.h]
2015-03-08 Avoid error on first DHT22 reading in loop()
    [NoteSensor.ino]
2015-03-09 Bug correction : wrong constant
    [NoteSensor.ino]
2015-03-09 Both: Add téléinformation client
    Gateway:
    Add informations about network on startup
    Node:
    Change default debug configuration (not activated)
    [configuration.h]
2015-03-13 Added moisture sensor Disable all sensor by default
    [configuration.h]
2015-03-14 Code improvements and bug correction
    Both
    Sending 'RADIO.DATALEN', better to understand than 'i' variable
    Node
    Display program name and node ID at startup
    Remove unused variable and move sensor specific inside '#ifdef'
    Move DHT22 data sending if DHT read succeed
    Add a debug data for TIC
    BUG : Put radio module in sleep mode before uC sleep and node after each data transmitting
    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
    [configuration.h]
2015-09-26 Add BMPXXX barometric pressure sensor
    [configuration.h]
2016-02-01 Add hardware source files NoteRF V0.3
    [NoteRF_0.3.brd, NoteRF_0.3.sch]
2020-02-14 Switch to PIO & add ST tof sensor
    [configuration.h]
2020-02-14 Switch gateway to PIO
    [configuration.h]

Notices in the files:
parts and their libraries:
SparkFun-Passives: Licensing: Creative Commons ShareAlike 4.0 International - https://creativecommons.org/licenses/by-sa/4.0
